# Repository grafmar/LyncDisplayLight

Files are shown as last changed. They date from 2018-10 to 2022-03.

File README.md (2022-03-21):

# LyncDisplayLight
This device is just a simple RGB-LED with a display which can be controlled by the virtual serial port on its USB connection.

In combination with the appropriate desktop application [Lync-Presence-Bridge](https://github.com/grafmar/Lync-presence-bridge)
it shows the active Lync / Skype for Business state and in the case of a call or chat it displays the counterpart of the
conversation. This is especially useful, if the monitor is locked. That's why I implemented this device.

With the time Lync or Skype for Business is no more state of the art and Microsoft introduced Teams. Therefore I implemented a
the desktop application [PresenceBridge](https://github.com/grafmar/PresenceBridge) to cover that connectivity. Not all
functionalities are implemented, yet, but at least the availability status is shown on the LED.

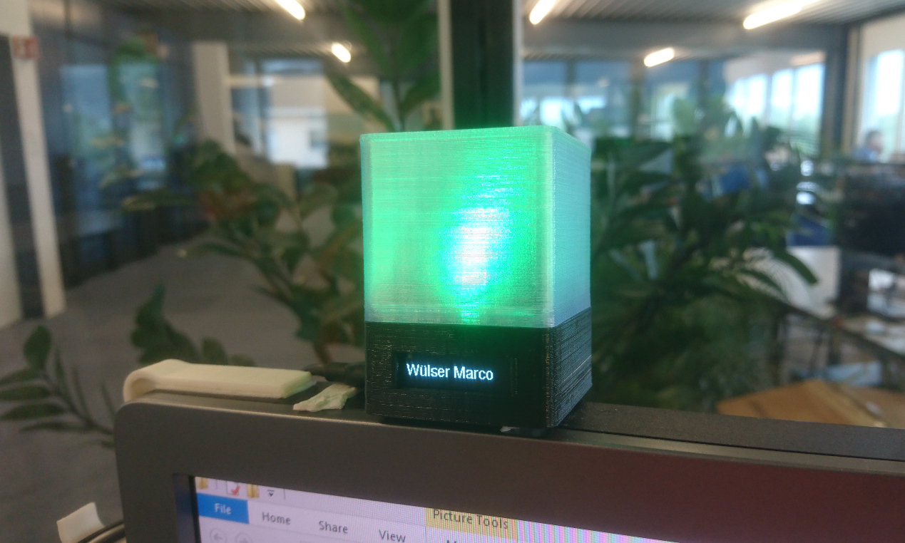
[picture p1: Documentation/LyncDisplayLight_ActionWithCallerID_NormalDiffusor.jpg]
LyncDisplayLight in action


## SW-Protocol
To control the LyncDisplayLight the specific protocol string followed by a new-line character (ASCII 0x0A)
can be sent through the serial port at a speed of 115200 baud. The protocol string just a key-word
followed by a colon and then the parameters:

| Keyword | Parameters | Description |
| :--- | :--- | :--- |
| rgb | red[0..255], green[0..255], blue[0..255] | Set the color of the cube light |
| callerid | string to display | Sets the Text on the Display. Send empty string to clear the display |

So to set the Color to yellow (red=255, green=255, blue=0) just set the string: `rgb:255,255,0\n`

To set a display text send the string: `callerid:John Doe\n`

## SW-Requirements
* [Arduino IDE](https://www.arduino.cc/en/main/software)
* [ESP8266 board support](https://github.com/arduino/Arduino/wiki/Unofficial-list-of-3rd-party-boards-support-urls): http://arduino.esp8266.com/stable/package_esp8266com_index.json
* Adafruit_NeoPixel library
* Adafruit_GFX library
* Adafruit_SSD1306 library
* [Visual Studio](https://visualstudio.microsoft.com/) to have a comfortable IDE
* [Visual Micro](https://www.visualmicro.com/) to integrate Arduino IDE in Visual Studio

## Hardware
The hardware consists of:
* Wemos D1 mini (available on [Aliexpress](https://www.aliexpress.com/item/D1-mini-Mini-NodeMcu-4M-bytes-Lua-WIFI-Internet-of-Things-development-board-based-ESP8266-by/32644199530.html))
* WS2812b board for Wemos D1 mini (available on [Aliexpress](https://www.aliexpress.com/item/WS2812B-RGB-expansion-board-for-D1-mini-BMP180/32806935855.html))
* 128x32 OLED display SSD1306 (soldered) (available on [Aliexpress](https://www.aliexpress.com/item/0-91-Inch-128x32-IIC-I2C-White-Blue-OLED-LCD-Display-DIY-Module-SSD1306-Driver-IC/32879702750.html))

### Wiring
The WS2812b board stacks just on top of the Wemos D1 mini. The connector of the LED has to be
unsoldered and then the OLED has to be soldered directly using wires. I wired it up to the
WS2812b board.

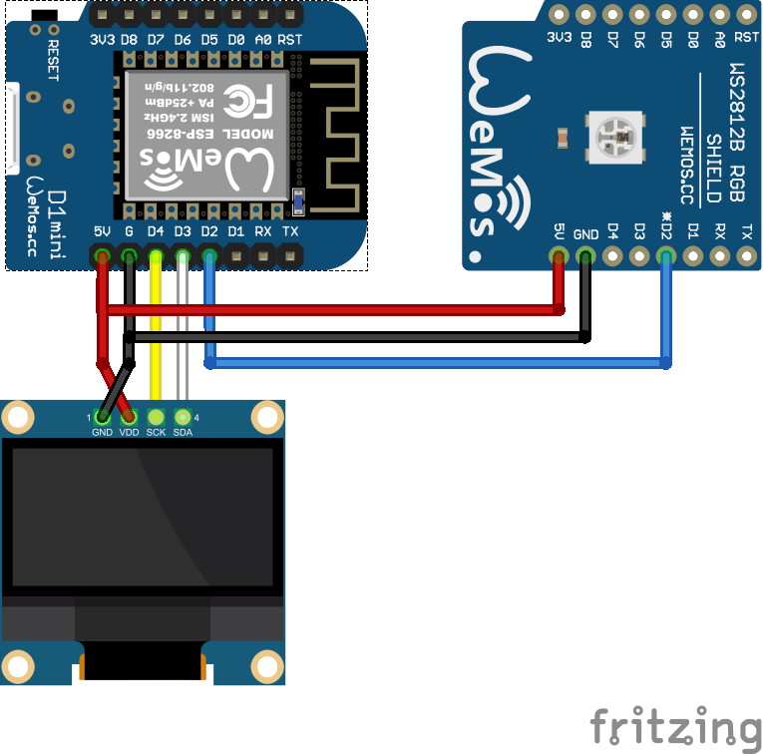
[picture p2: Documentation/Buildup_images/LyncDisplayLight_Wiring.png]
Wiring of the Lync Display Light
 

## Housing / Enclosure
The housing is 3D printed using black PLA for the base and clear PLA for the diffusor. I also
made different types with smaller diffusors or special diffusors. Even though the diffusor cube
is 42x42mm it doesn't look square if the height is also 42mm. Therefore I changed the hight to
38mm which looks sqare. This is the diffusor height I used most often.

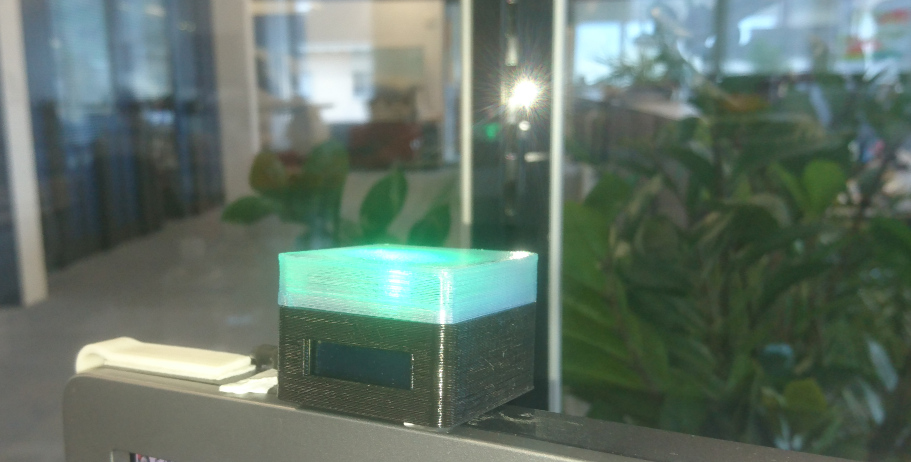
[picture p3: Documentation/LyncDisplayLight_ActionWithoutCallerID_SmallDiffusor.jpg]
LyncDisplayLight with small diffusor
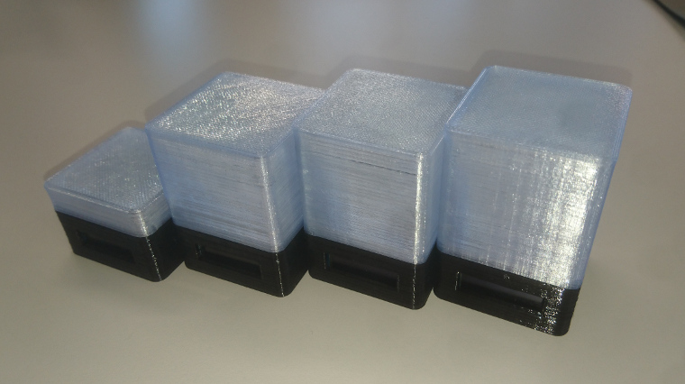
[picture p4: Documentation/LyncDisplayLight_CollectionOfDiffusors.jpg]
Different diffusors
 
  
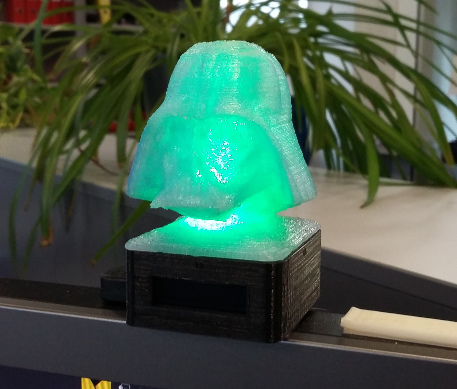
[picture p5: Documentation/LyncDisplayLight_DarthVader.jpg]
LyncDisplayLight with Darth Vader diffusor
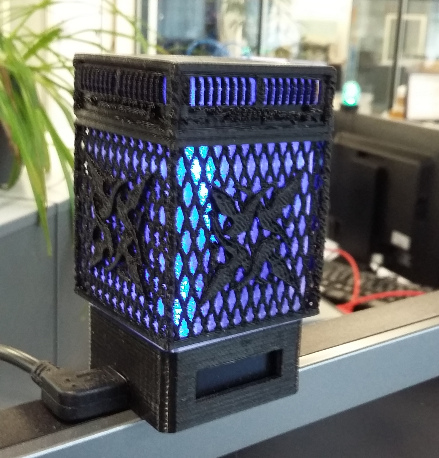
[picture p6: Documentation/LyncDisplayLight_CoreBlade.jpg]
LyncDisplayLight with Bass Guitar Amplifier diffusor
 

## Buildup
A description how to build this device is available in the [documentation](Documentation/buildup.md).

## Author
[Marco Graf](https://github.com/grafmar)

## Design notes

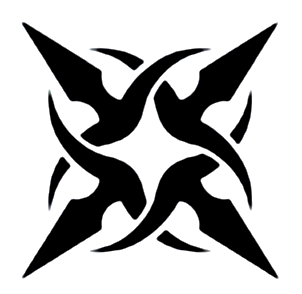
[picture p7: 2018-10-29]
housing/Beck/Coreblade.png

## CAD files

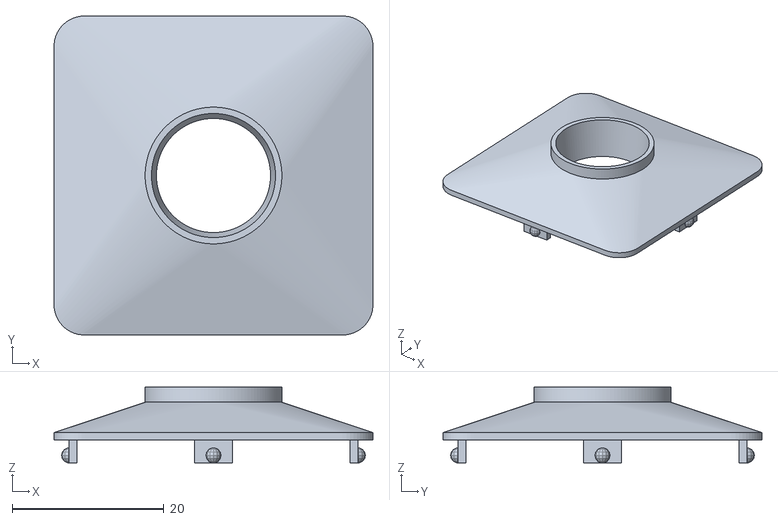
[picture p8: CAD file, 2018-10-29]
housing/DarthVaderDiffusor/DarthVaderDiffusor_base.stl
42.0 x 42.0 x 10.0

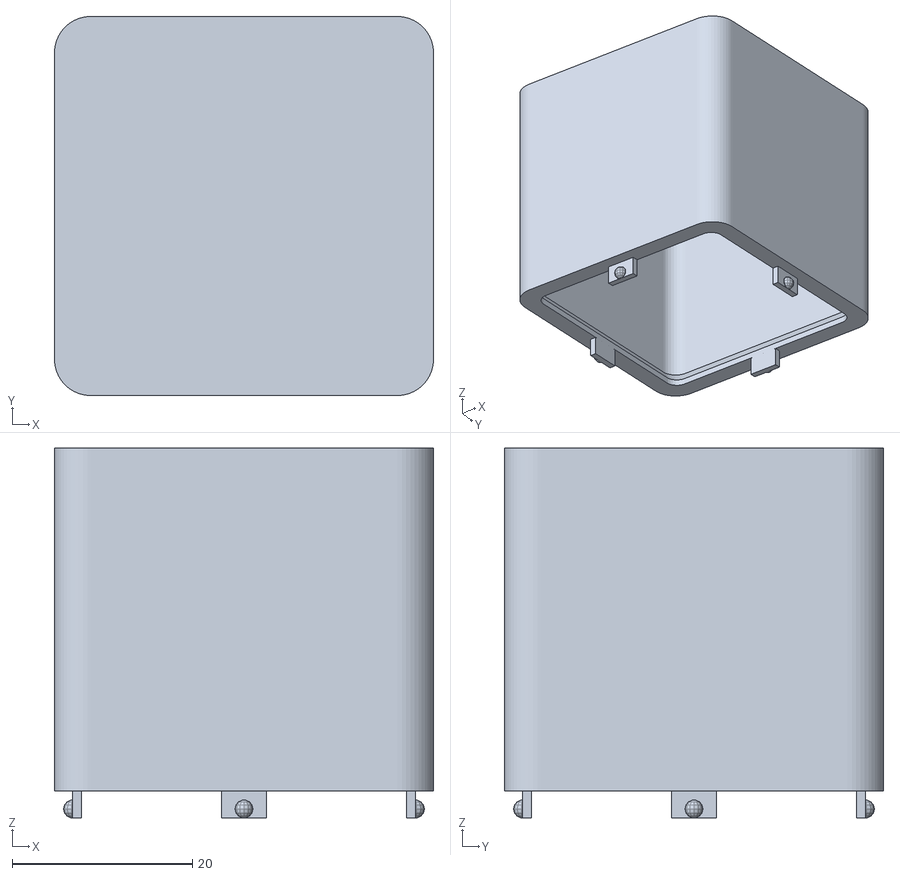
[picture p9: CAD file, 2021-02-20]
housing/LyncDisplayLight_Diffusor_38mm_1.5mmThick.stl
42.0 x 42.0 x 41.0

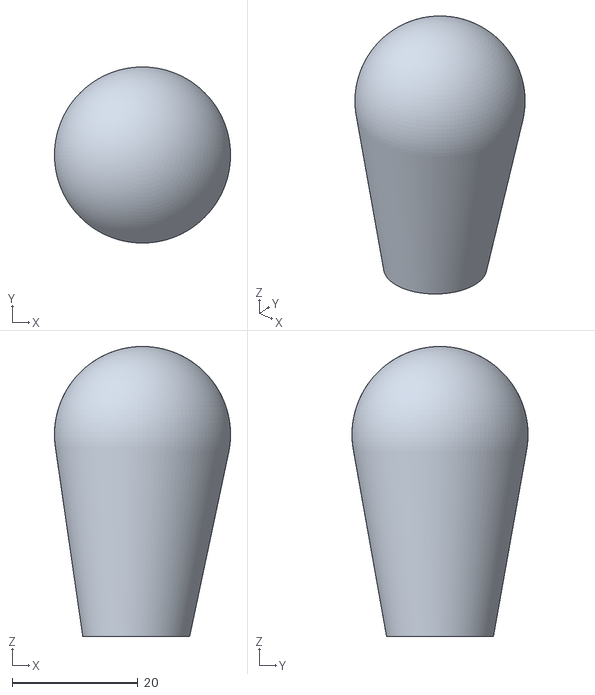
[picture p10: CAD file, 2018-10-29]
housing/DarthVaderDiffusor/DarthVaderDiffusor_cutOut.stl
28.0 x 28.0 x 46.1

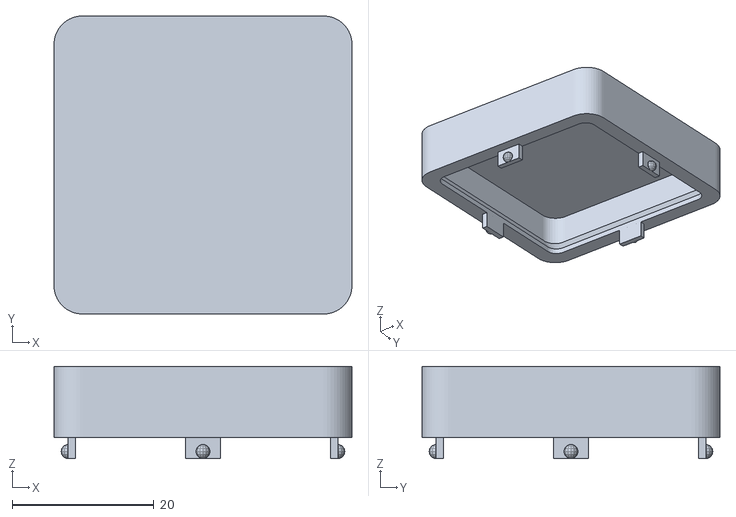
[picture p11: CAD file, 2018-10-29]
housing/LyncDisplayLight_Diffusor_10mm.stl
42.0 x 42.0 x 13.0

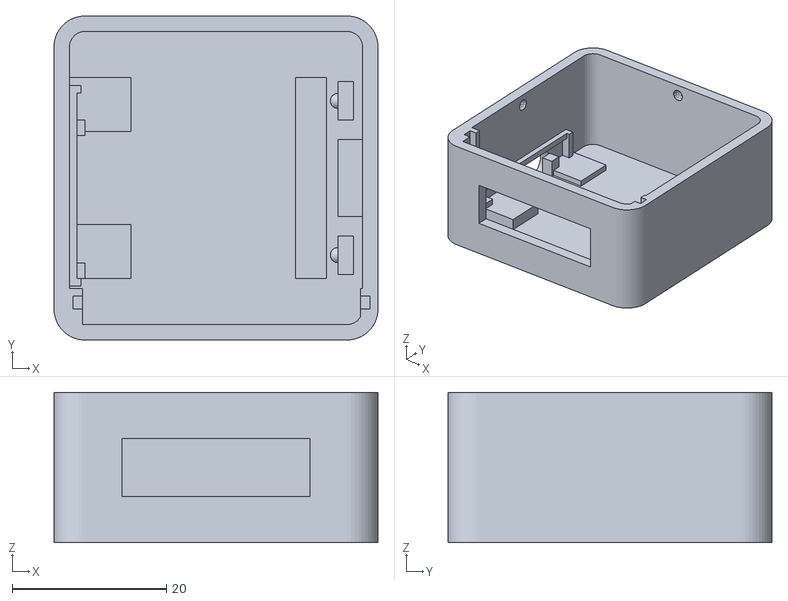
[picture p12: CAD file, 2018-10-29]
housing/LyncDisplayLight_BottomPart_2mmHook.stl
42.0 x 42.0 x 19.5

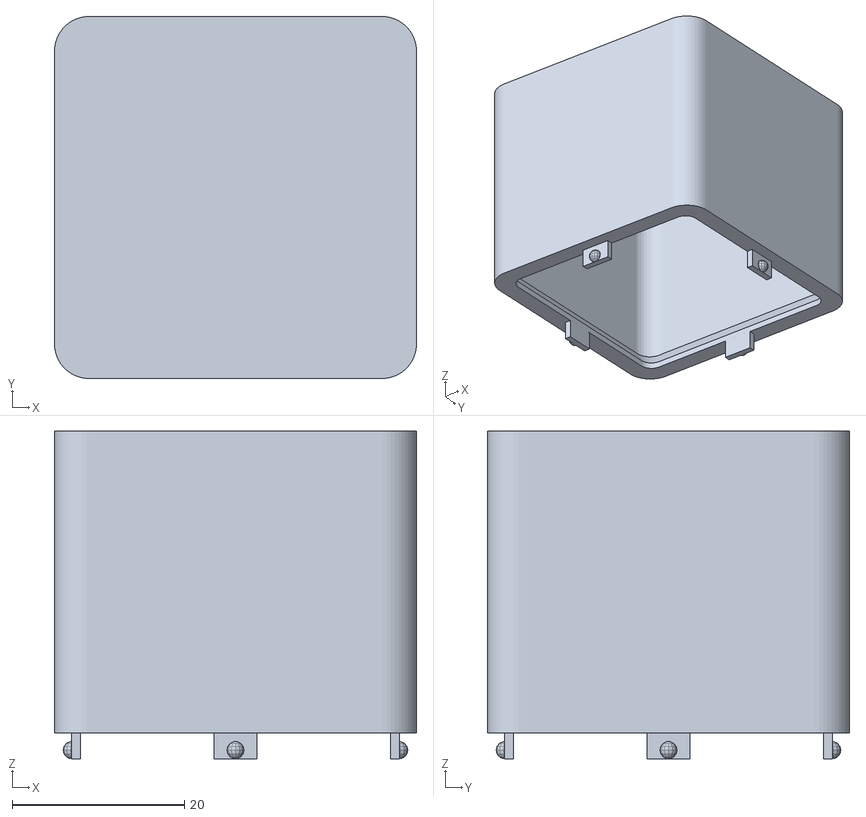
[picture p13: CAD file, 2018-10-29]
housing/LyncDisplayLight_Diffusor_35mm.stl
42.0 x 42.0 x 38.0

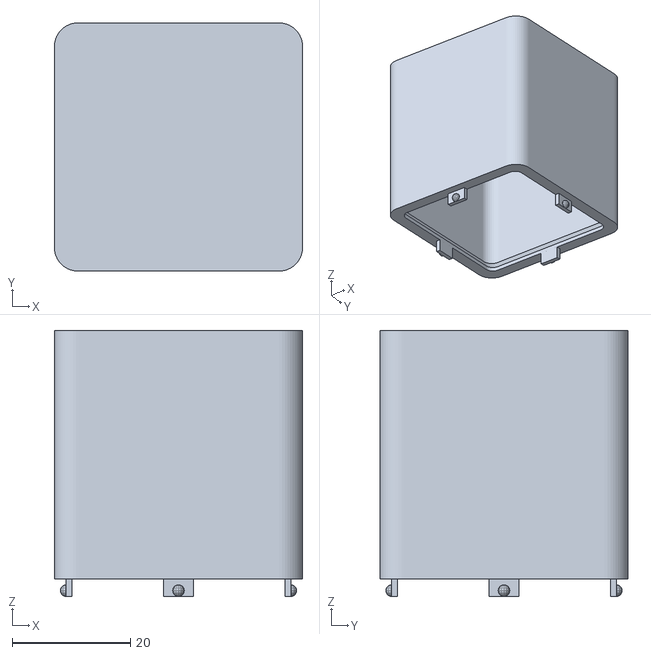
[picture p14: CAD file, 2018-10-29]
housing/LyncDisplayLight_Diffusor_42mm.stl
42.0 x 42.0 x 45.0

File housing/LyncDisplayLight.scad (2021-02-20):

side=42;
//diffusorHeight=side; // 42mm
diffusorHeight=side-4; // 38mm
//diffusorHeight=side-7; // 35mm
//diffusorHeight=10; // 10mm
rounding=4;
wall=2;
bottomHeight=18;
$fs=.5;
$fa=3;
diffThick=2;

/*
translate([0,0,0.1]){color("PaleTurquoise",1){diffusor();}}
color("DarkSlateGray"){bottomPart();}
*/
diffusor();
//diffusorSpreader();
bottomPart();

module diffusorSpreader() {
  y=1/(sin(atan2(side/2-1,diffusorHeight/2)));
  echo(y);
  difference() {
    translate([0,0,bottomHeight+diffusorHeight/2-.5]) {cylinder(r1=0,r2=side/2-1,h=diffusorHeight/2,center=false);}
    translate([0,0,bottomHeight+diffusorHeight/2+y-.5]) {cylinder(r1=0,r2=side/2-1,h=diffusorHeight/2,center=false);}
  }
}

module diffusor() {
    color("LightCyan",1.0){
        // upper hollow
        difference() {
            offset = side/2-rounding;
            hull() { for(a=[0:90:360]) { rotate([0,0,a]) {
                translate([offset,offset,bottomHeight]) {cylinder(r=rounding,h=1,center=false);}
                translate([offset,offset,bottomHeight+diffusorHeight-1]) {cylinder(r=rounding,h=1,center=false);}
            }}}
            hull() { for(a=[0:90:360]) { rotate([0,0,a]) {
                translate([offset,offset,bottomHeight-1]) {cylinder(r=rounding-diffThick,h=1,center=false);}
                translate([offset,offset,bottomHeight-1+diffusorHeight-1]) {cylinder(r=rounding-diffThick,h=1,center=false);}
            }}}
        }
        
        // bottom step
        difference() {
            hull() { for(a=[0:90:360]) { rotate([0,0,a]) {
                offset = side/2-rounding;
                translate([offset,offset,bottomHeight]) {cylinder(r=rounding,h=5,center=false);}
            }}}
            hull() { for(a=[0:90:360]) { rotate([0,0,a]) {
                offset = side/2-3-2;
                translate([offset,offset,bottomHeight-1]) {cylinder(r=2,h=5+2,center=false);}
            }}}
            hull() { for(a=[0:90:360]) { rotate([0,0,a]) {
                offset = side/2-3-2;
                offset2 = side/2-(rounding-1);
                translate([offset,offset,bottomHeight+1]) {cylinder(r=2,h=3+3,center=false);}
                translate([offset2,offset2,bottomHeight+1+4]) {cylinder(r=rounding-1,h=1,center=false);}
            }}}
        }
        
        // Hooks
        for(a=[0:90:360]) { rotate([0,0,a]) {
            translate([side/2-3,-2.5,bottomHeight-3]){cube([1,5,3]);}
            translate([side/2-2,0,bottomHeight-2]){sphere(r=1);}
        }}
    }
}


module bottomPart() {
    color([.2,.2,.2],1.0){

        bWall = 1.5; // floor thickness
        dispBoardWidth=6.11+24.38+7.51;
        
        // upper hollow
        difference() {
            offset = side/2-rounding;
            hull() { for(a=[0:90:360]) { rotate([0,0,a]) {
                translate([offset,offset,-bWall]) {cylinder(r=rounding,h=1,center=false);}
                translate([offset,offset,bottomHeight-1]) {cylinder(r=rounding,h=1,center=false);}
            }}}
            hull() { for(a=[0:90:360]) { rotate([0,0,a]) {
                translate([offset,offset,0]) {cylinder(r=rounding-wall,h=1,center=false);}
                translate([offset,offset,bottomHeight+1]) {cylinder(r=rounding-wall,h=1,center=false);}
            }}}
            
            // Hook holes
            for(a=[0:90:360]) { rotate([0,0,a]) {
                translate([side/2-2,0,bottomHeight-2]){sphere(r=1);}
            }}
            
            // USB plug hole
            hull() {
                translate([-(side/2-wall-.1),7/2+1,3-2.5/2]) {rotate([0,90,180]) {cylinder(d=6,h=wall+1);}}
                translate([-(side/2-wall-.1),-7/2+1,3-2.5/2]) {rotate([0,90,180]) {cylinder(d=6,h=wall+1);}}
            }
            
            // Display hole
            translate([-24.4/2,-(side/2+wall),2.96+1.5]){cube([24.4,3*wall,7.58]);}
            // Dispaly board
            translate([-6.11-24.38/2-0.5/2,-side/2+wall+2,0.01]){cube([dispBoardWidth+.5,1.7,bottomHeight]);}
        }
        
        // Processor board support
        translate([-(side/2-wall)+34.3-5,-26/2,0]){cube([4,26,3]);} // back bottom
        translate([-(side/2-wall)+34.3+.5,-10/2,0]){cube([4,10,5]);} // back back
        translate([-(side/2-wall)+34.3+.5,20/2,0]){hook();} // back hook
        translate([-(side/2-wall)+34.3+.5,-20/2,0]){hook();} // back hook
        translate([-(side/2-wall),26/2-2-5.5,0]){cube([2,2,3]);} // front bottom 1
        translate([-(side/2-wall),26/2-7,0]){cube([8,7,1]);} // front bottom 1.2
        translate([-(side/2-wall),-26/2,0]){cube([2,2,3]);} // front bottom 2
        translate([-(side/2-wall),-26/2,0]){cube([8,7,2]);} // front bottom 2.2
        translate([-(side/2-wall)-0.01,-26/2,3+1.7]){cube([1,26-2,1]);} // front top
        translate([-(side/2-wall),26/2-2,0]){cube([1.5,1,3+1.7+1]);} // front side 1
        translate([-(side/2-wall),-26/2-1,0]){cube([1.5,1,3+1.7+1]);} // front side 2
        
        // Display support
        difference() {
            union() {
                translate([-6.11-24.38/2-1,-side/2+wall+2-2,0]){cube([2,1.7+3,bottomHeight]);}
                translate([24.38/2+7.51-1,-side/2+wall+2-1,0]){cube([2,1.7+2,bottomHeight]);}
            }
            translate([-6.11-24.38/2-0.5/2,-side/2+wall+2,1.5]){cube([dispBoardWidth+.5,1.7,2*bottomHeight]);}
        }
    }
}

module hook() {
    translate([0,-2.5,0]){ // back hook
        cube([2,5,3+1.5+2]);
        translate([0,5/2,3+1+0.5]){
            difference() {
                sphere(r=1,center=true);
                translate([2.01,0,0]){cube([4,4,4],center=true);}
            }
        }
    }
}

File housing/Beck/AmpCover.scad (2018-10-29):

b=46;
ampH=15.4;
cabH=b;
thick=0.8;

cabCube();
translate([0,0,b]){ampCube();}

module cabCube() {
    translate([0,0,0]){rotate([90,0,0]){translate([-1,0,-1]){cabFront();}}}
    translate([b-2,0,0]){rotate([90,0,90]){translate([-1,0,-1]){cabFront();}}}
    translate([b-2,b-2,0]){rotate([90,0,180]){translate([-1,0,-1]){cabFront();}}}
    translate([0,b-2,0]){rotate([90,0,270]){translate([-1,0,-1]){cabFront();}}}
}

module cabFront() {
    h=cabH;
    cornerPositions = [[1,1,1], [1,h-1,1], [b-1,h-1,1], [b-1,1,1]];
    for (i=[0:3]) {
        hull() {
            translate(cornerPositions[i]){sphere(d=2,$fs=.3);}
            translate(cornerPositions[(i+1)%4]){sphere(d=2,$fs=.3);}
        }
    }
    // "plate"
    difference() {
        translate([1,1,0]){cube([b-2,h-2+2,thick]);}
        translate([2,2,-thick/2]){cube([b-4,h-4,2*thick]);}
    }
    // grid
    translate([1,1,0]){grid(b-2,h-2,thick);}
    // coreblade emblem
    color("SlateGray",1.0){
        translate([(b-30)/2,(b-30)/2,1]){scale([0.3,0.3,1]){
            linear_extrude(height = 2, center = true, convexity = 10){import("Coreblade.dxf", convexity=3);}
        }}
    }
}

module grid(x,y,t) {
    rot1=20;
    rot2=-20;
    l=x+y;
    rod=1;
    space=2.5;
    
    intersection(){
        for(xx = [-l:(rod+space):l]){
            rotate([0,0,rot1]){translate([xx,0,t/2]){cube([rod,2*l,t],center=true);}}        rotate([0,0,rot2]){translate([xx+x,0,t/2]){cube([rod,2*l,t],center=true);}}
        }
        translate([0,0,-t]){cube([x,y,3*t]);}
    }
}

module ampCube() {
    translate([0,0,0]){rotate([90,0,0]){translate([-1,0,-1]){ampFront();}}}
    translate([b-2,0,0]){rotate([90,0,90]){translate([-1,0,-1]){ampFront();}}}
    translate([b-2,b-2,0]){rotate([90,0,180]){translate([-1,0,-1]){ampFront();}}}
    translate([0,b-2,0]){rotate([90,0,270]){translate([-1,0,-1]){ampFront();}}}
    translate([0,0,ampH-1]){cube([b-2,b-2,1]);}
}

module ampFront() {
    h=ampH;
    cornerPositions = [[1,1,1], [1,h-1,1], [b-1,h-1,1], [b-1,1,1]];
    for (i=[0:3]) {
        hull() {
            translate(cornerPositions[i]){sphere(d=2,$fs=.3);}
            translate(cornerPositions[(i+1)%4]){sphere(d=2,$fs=.3);}
        }
    }
    
    // plate
    difference() {
        union() {
            translate([1,1,0]){cube([b-2,h-2,thick]);}
            translate([1+(b-2)/2,6+7.2/2,1]){scale([1,7.2,1]){rotate([0,90,0]){cylinder(d=1,h=b-2,center=true,$fs=.1);}}}
        }
        for (i=[0:7]) {
            translate([4.9+i*(1.7+0.5),6.6,-thick/2]){roundCube(1.7,6,3*thick,0.4);}
            translate([4.9+19.5+i*(1.7+0.5),6.6,-thick/2]){roundCube(1.7,6,3*thick,0.4);}
        }
    }
    // Knobs and switches 1.48 1.65 1.55
    color("SlateGray",1.0){
        translate([5.5,4,0.8+.5]){rotate([-15,0,0]){cylinder(d=0.6,h=1,center=false,$fs=.2);}}
        translate([7.4,4,0.8+.5]){rotate([15,0,0]){cylinder(d=0.6,h=1,center=false,$fs=.2);}}
        knobPositions_x = [10.5, 14.5,16.1,17.7,19.3,20.9,22.5, 24.3,25.9,27.5, 29.3,30.9,32.5, 34.3];
        for(knobPosition_x = knobPositions_x) {
            translate([knobPosition_x,4,1]){cylinder(d=1,h=1.2,center=false,$fs=.3);}
        }
        translate([36.5+0.8,4,1]){
            cylinder(d=1.6,h=0.8,center=false,$fs=.3);
            rotate([0,0,-15]){translate([-.25,-0.8,0]){cube([0.5,1.8,1.5]);}}
        }
    }
}

module roundCube(x,y,t,r) {
    points = [[r,r,0],[x-r,r,0],[x-r,y-r,0],[r,y-r,0]];
    hull() {
        for(i=[0:3]){
            translate(points[i]){cylinder(r=r,h=t,$fs=.1);}
        }
    }
}

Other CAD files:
housing/Beck/Coreblade.dxf
housing/LyncDisplayLight_Diffusor_38mm.stl
housing/DarthVaderDiffusor/DarthVaderDiffusor.scad

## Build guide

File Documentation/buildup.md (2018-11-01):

# Buildup of Lync-Display-Light

## Electronics
Solder the female pin header to the Wemos D1 mini board:

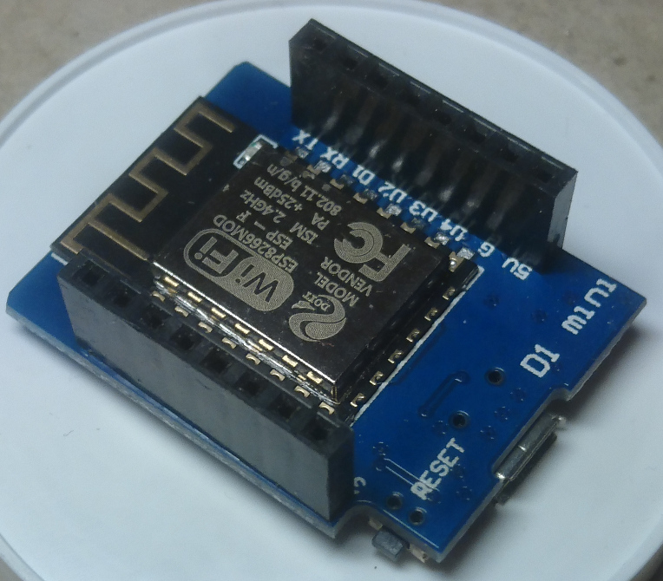
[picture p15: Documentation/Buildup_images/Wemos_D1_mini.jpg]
Wemos D1 mini with female pin headers


The WS2812b board has to be shortened at the lower part to fit into the housing. Then the pin
headers can be soldered.

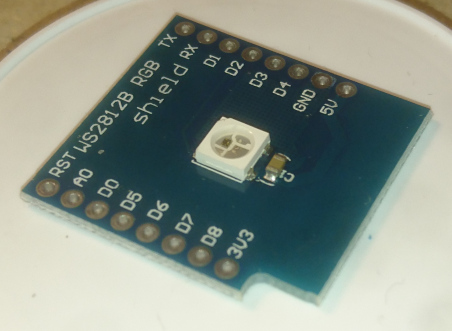
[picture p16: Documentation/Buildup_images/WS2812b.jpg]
WS2812b original
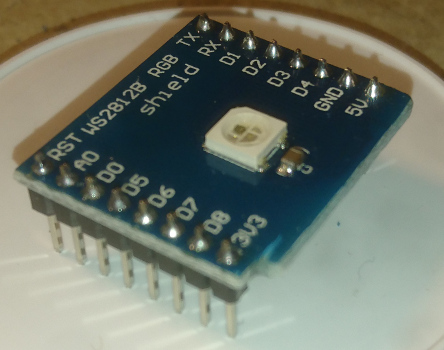
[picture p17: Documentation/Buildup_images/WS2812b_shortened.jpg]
WS2812b shortened


To connect the display the black plastic of the connector has to be removed for the pins "5V", "GND", "D4" and "D3":

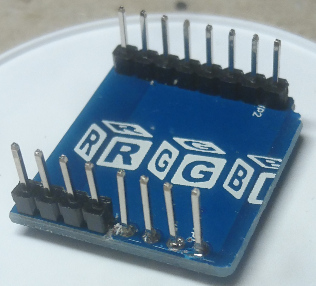
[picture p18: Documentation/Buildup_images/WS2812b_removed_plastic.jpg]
WS2812b removed plastic


Then four short wires can be soldered from the WS2812b board to the SSD1306 OLED 128x32 I2C. I used
a ribbon cable for this purposes.

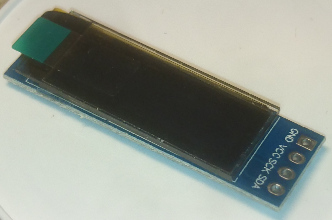
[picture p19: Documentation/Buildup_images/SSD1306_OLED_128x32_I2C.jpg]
SSD1306 OLED 128x32 I2C
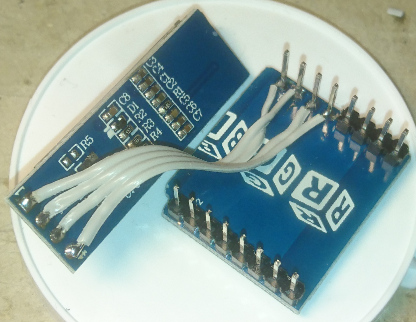
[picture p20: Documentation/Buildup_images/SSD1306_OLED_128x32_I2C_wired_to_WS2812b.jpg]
OLED wired to WS2812b


## Put into housing
The Wemos D1 mini board can be inserted into the bottom part of the housing with the USB
connector first and should then just snap in.

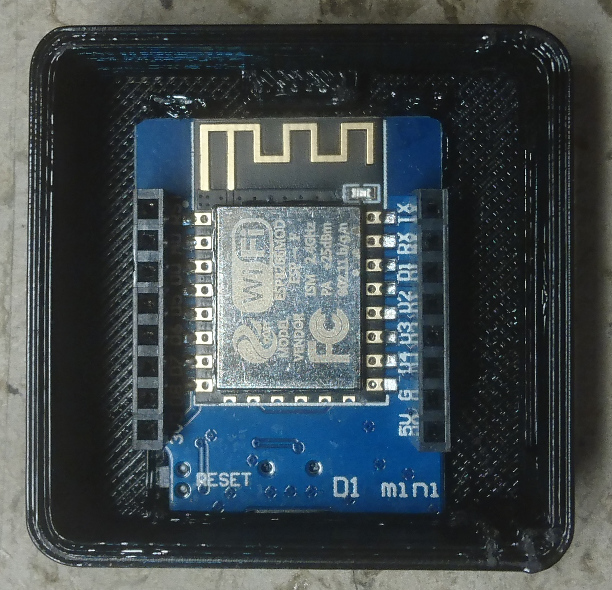
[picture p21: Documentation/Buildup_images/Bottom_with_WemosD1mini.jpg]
Wemos D1 mini board in bottom part


Remove the protective foil from the display. Then the display can be inserted into the groove
of the housing. Possibly the flat black cable foil on the right has to be folded to be able
to insert it.

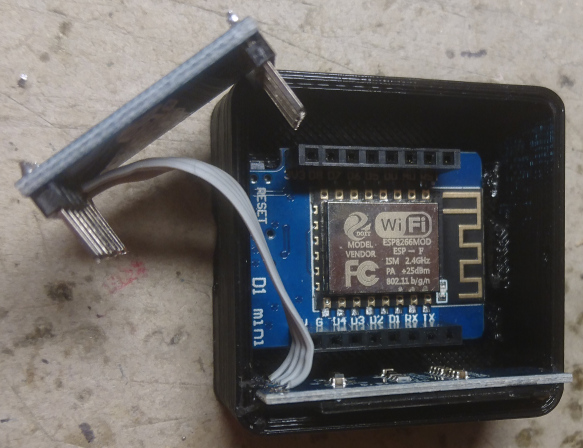
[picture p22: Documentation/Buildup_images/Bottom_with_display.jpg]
Bottom part with display


Then the WS2812b board can be connected on top of the Wemos D1 mini.

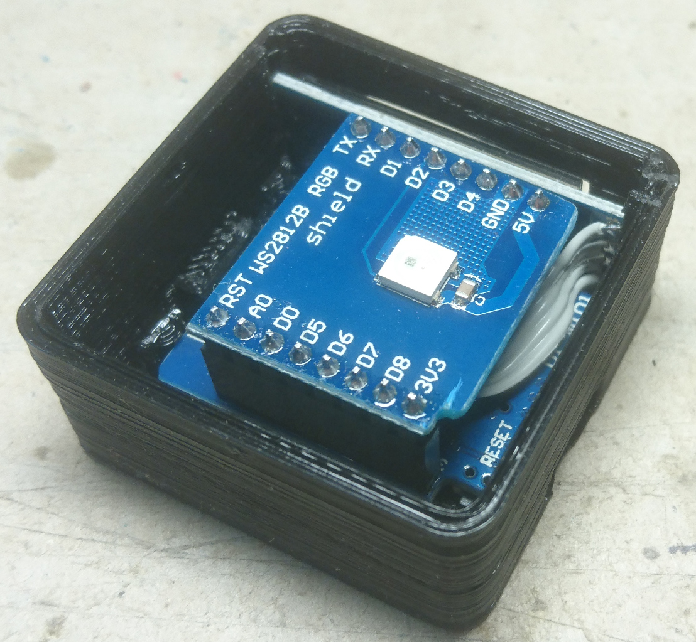
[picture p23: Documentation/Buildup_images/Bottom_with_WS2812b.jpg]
Bottom part with WS2812b


Put the desired diffusor on top of the bottom part in an angle of 45°. Then just turn it to snap
in the diffusor to the bottom part. Connect the Lync display light to your PC and program it.
When it starts up, it sets the light to a dimm blue and the Welcome message is displayed.

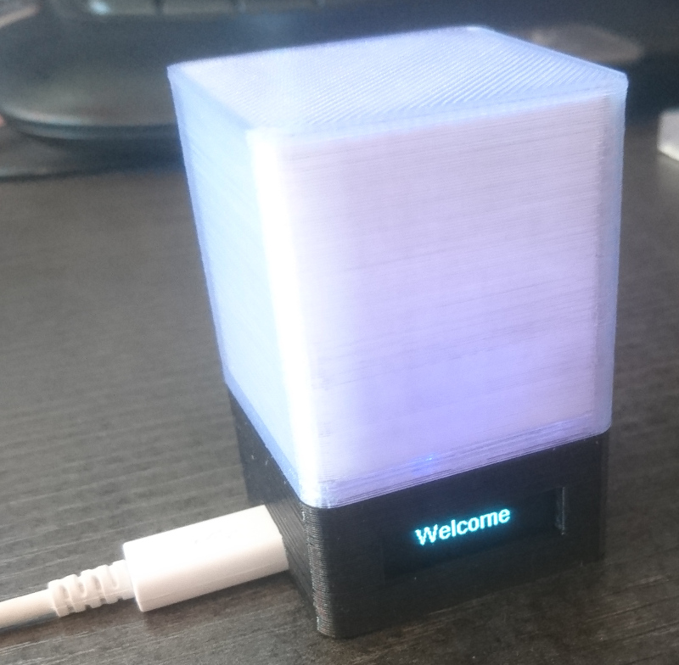
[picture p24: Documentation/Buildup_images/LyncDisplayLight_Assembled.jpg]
LyncDisplayLight completely assembled


## Author
[Marco Graf](https://github.com/grafmar)

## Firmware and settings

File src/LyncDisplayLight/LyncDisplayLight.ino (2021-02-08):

#include <ESP8266WiFi.h>
#include <Wire.h>
#include <SPI.h>
#include <Adafruit_GFX.h>
#include <Adafruit_SSD1306.h>
#include <Adafruit_NeoPixel.h>
#include "FreeSans9pt8b.h"


#define OLED_SDA    D3
#define OLED_SCK    D4
#define OLED_RESET  D5
#define LED_PIN     D2

Adafruit_SSD1306 display(128, 32, &Wire, OLED_RESET);
Adafruit_NeoPixel ledPixel = Adafruit_NeoPixel(1, LED_PIN, NEO_GRB + NEO_KHZ800);
String inData;

uint32_t lastUpdate;
#define UPDATE_THRESHOLD 120000UL

void OnSetLed(uint8_t red, uint8_t green, uint8_t blue) {
    ledPixel.setPixelColor(0, ledPixel.Color(red, green, blue));
    ledPixel.show();
}


void OnSetDisplay(String callerid) {
    display.clearDisplay();
    display.setCursor(0, 21);
    display.println(callerid);
    display.display();
}


void setup() {
    // Listen on serial connection for messages from the PC
    Serial.begin(115200);

    // Turn WiFi off
    WiFi.mode(WIFI_OFF);

    delay(2000);  // delay to sattle all voltages (for display)

    // setup RGB-LED
    ledPixel.begin();
    ledPixel.setPixelColor(0, ledPixel.Color(0, 0, 50));
    ledPixel.show();

    delay(2000);  // delay to sattle all voltages (for display)

    Wire.begin(OLED_SDA, OLED_SCK); // Initialize I2C for OLED Display (GPIO0 and GPIO2)
    display.begin(SSD1306_SWITCHCAPVCC, 0x3C);  // initialize with the I2C addr 0x3D (for the 128x64)
    display.setFont(&FreeSans9pt8b);
    display.setTextColor(WHITE);
    display.setTextWrap(false);
    OnSetDisplay("     Welcome");
    delay(2000);
    OnSetDisplay("");
    lastUpdate = millis();
}


void loop() {
    while (Serial.available() > 0) {
        char recieved = Serial.read();
        inData += recieved;

        // Process message when new line character is recieved
        if ((recieved == '\n') || (recieved == '\r')) {
            if (inData.startsWith("rgb:")) {
                lastUpdate = millis();
                int ind;
                uint8_t red;
                uint8_t green;
                uint8_t blue;

                ind = inData.indexOf(',');  //finds location of first ,
                red = inData.substring(4, ind).toInt();
                inData = inData.substring(ind + 1);
                ind = inData.indexOf(',');  //finds location of first ,
                green = inData.substring(0, ind).toInt();
                inData = inData.substring(ind + 1);
                ind = inData.indexOf(',');  //finds location of first ,
                blue = inData.substring(0, ind).toInt();

                OnSetLed(red, green, blue);
            }
            else if (inData.startsWith("callerid:")) {
                OnSetDisplay(inData.substring(9));
            }

            inData = ""; // Clear recieved buffer
        }
    }

    // Nothing communicating: Clear display and show light blue -> OFF
    if (millis() - lastUpdate > UPDATE_THRESHOLD) {
        lastUpdate = millis();
        ledPixel.setPixelColor(0, ledPixel.Color(0, 0, 50));
        ledPixel.show();
        OnSetDisplay("");
    }
}

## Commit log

2018-10-29 Adding images and 3D-Models of housing
    [AmpCover.scad, Coreblade.dxf, DarthVaderDiffusor.scad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]
2018-11-01 Extend documentation
    [LyncDisplayLight_Wiring.fzz]
2021-02-08 Moved source files to be able to open with arduino IDE
2021-02-08 Allowing carriage return or line feed to end the command to be more versatile for usages
2021-02-20 Add thickness of diffusor to housing model
    [LyncDisplayLight.scad, LyncDisplayLight_Diffusor_38mm_1.5mmThick.stl]
